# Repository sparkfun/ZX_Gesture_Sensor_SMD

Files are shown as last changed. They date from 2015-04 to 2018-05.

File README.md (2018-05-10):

SparkFun ZX Distance and Gesture Sensor
========================================

ZX Gesture Sensor

[*ZX Gesture Sensor (13162)*](https://www.sparkfun.com/products/13162)

The ZX Sensor works by bouncing infrared (IR) beams of light from the two LEDs on either side 
off of an object above the sensor. The bounced light returns to the receiver in the center of
the sensor, and a microcontroller on the back of the sensor interprets the data. We can read 
the results using an I2C or UART connection.

Repository Contents
-------------------

* **/Hardware** - Eagle design files (.brd, .sch)
* **/Libraries** - Arduino library and example code. For the most recent updates, make sure to check out the GitHub repo for the Arduino library linked below.
* **/Production** - Production panel files (.brd)

Documentation
--------------
* **[Library](https://github.com/sparkfun/SparkFun_ZX_Distance_and_Gesture_Sensor_Arduino_Library)** - Arduino library for the ZX Distance and Gesture Sensor.
* **[Hookup Guide](https://learn.sparkfun.com/tutorials/zx-distance-and-gesture-sensor-smd-hookup-guide)** - Basic hookup guide for the ZX Gesture Sensor.

License Information
-------------------

This product is _**open source**_! 

Please review the LICENSE.md file for license information. 

If you have any questions or concerns on licensing, please contact techsupport@sparkfun.com.

Distributed as-is; no warranty is given.

- Your friends at SparkFun.

__In Collaboration in XYZ Interactive__

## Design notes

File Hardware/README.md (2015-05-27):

SparkFun <PRODUCT NAME> Design Files
=====================================

The .sch and .brd files hare are Eagle CAD schematic and PCB design files from SparkFun Electronics.
A freeware version of Eagle can be found [here](http://www.cadsoftusa.com/download-eagle/freeware/).

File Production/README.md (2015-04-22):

SparkFun <PRODUCT NAME> Production Files
=========================================

These are the production files SparkFun uses for printing PCBs.

License Information
-------------------
This product is open source! 

The hardware is released under [Creative Commons ShareAlike 4.0 International](https://creativecommons.org/licenses/by-sa/4.0/).

Please use, reuse, and modify these files as you see fit. Please maintain attribution to SparkFun Electronics and release anything derivative under the same license.

Distributed as-is; no warranty is given.

- Your friends at SparkFun.

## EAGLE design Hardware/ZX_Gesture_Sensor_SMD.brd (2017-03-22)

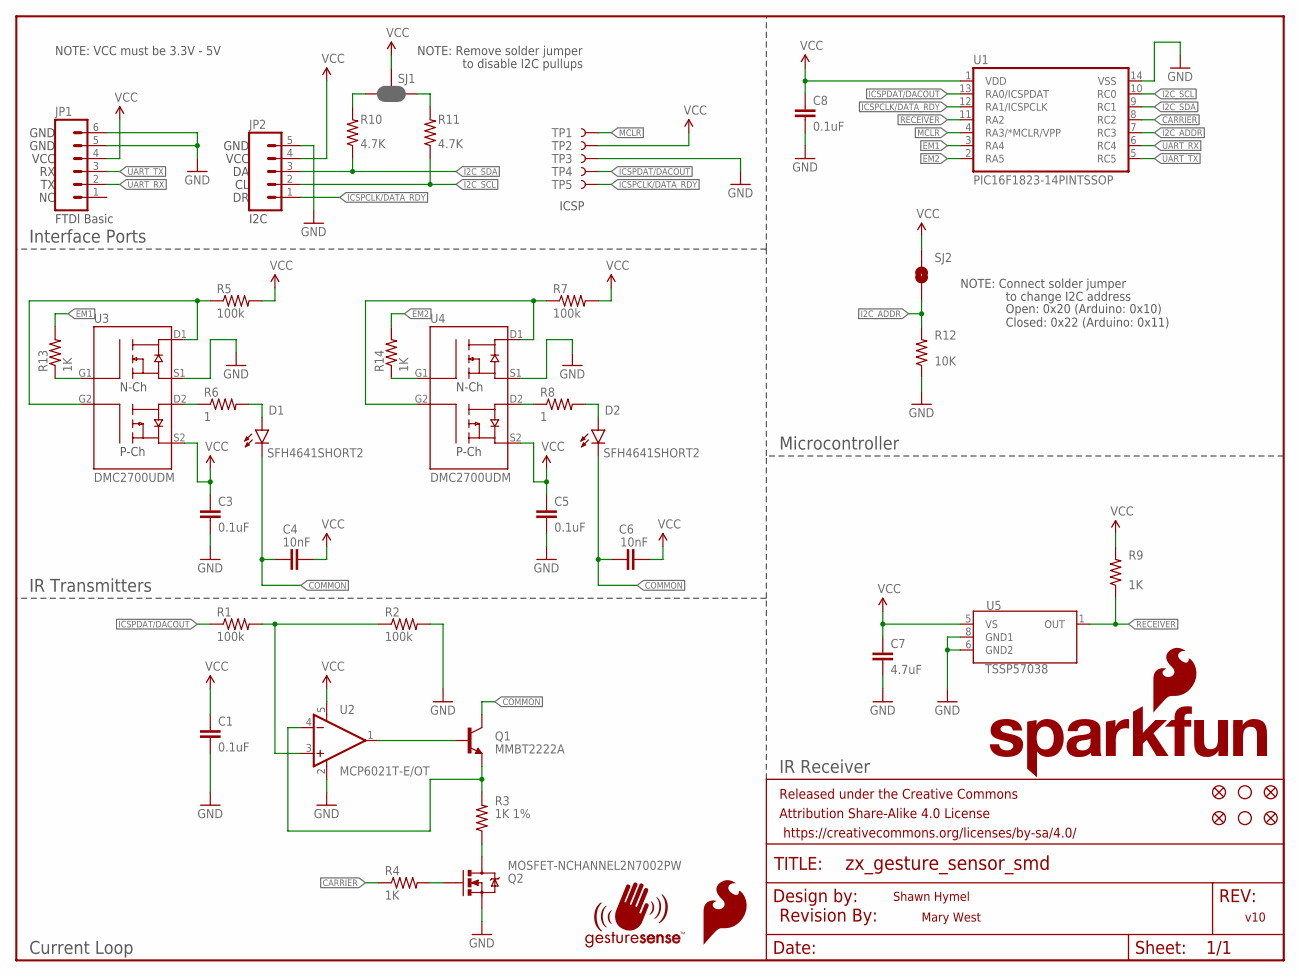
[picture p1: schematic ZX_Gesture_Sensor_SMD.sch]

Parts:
C1, C3, C5, C8: 0.1uF; 0603-CAP
C4, C6: 10nF; 0603-CAP
C7: 4.7uF; 0603-CAP
D1, D2: SFH4641SHORT2; SFH4641-SHORT2
FID1, FID2, FID3, FID4: FIDUCIALUFIDUCIAL; MICRO-FIDUCIAL
FRAME1: FRAME-LETTER; CREATIVE_COMMONS
JP1: M06NO_SILK_FEMALE_PTH; 1X06_NO_SILK
JP2: M05PTH; 1X05
LOGO1: REVISION
LOGO2: SFE_LOGO_FLAME.1_INCH; SFE_LOGO_FLAME_.1
Q1: MMBT2222A; SOT23-3
Q2: MOSFET-NCHANNEL2N7002PW; SOT323
R1, R2, R5, R7: 100k; 0603-RES
R3: 1K 1%; 0603-RES
R4, R9, R13, R14: 1K; 0603-RES
R6, R8: 1; 0603-RES
R10, R11: 4.7K; 0603-RES
R12: 10K; 0603-RES
SJ1: JUMPER-PAD-3-NC_BY_PASTE; PAD-JUMPER-3-NC_BY_PASTE_YES_SILK_FULL_BOX
SJ2: JUMPER-PAD-2-NOYES_SILK; PAD-JUMPER-2-NO_YES_SILK
STANDOFF1, STANDOFF2: STAND-OFF
TP1, TP2, TP3, TP4, TP5: TEST-POINT3X4; PAD.03X.04
U1: PIC16F1823-14PINTSSOP; TSSOP14
U2: MCP6021T-E/OT; SOT23-5
U3, U4: DMC2700UDM; SOT26
U5: TSSP57038; TSOP572
U$5: SFE_LOGO_NAME_FLAME.1_INCH; SFE_LOGO_NAME_FLAME_.1
U$6: GESTURESENSE_LOGOSTEXT; GESTURESENSE_TEXT

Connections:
CARRIER: R4.1, U1.8 (RC2)
COMMON: C4.1, C6.1, D1.C, D2.C, Q1.3 (C)
EM1: R13.2, U1.3 (RA4)
EM2: R14.2, U1.2 (RA5)
GND: C1.2, C3.2, C5.2, C7.2, C8.2, JP1.5, JP1.6, JP2.5, Q2.2 (S), R2.2, R12.1, TP3.P$1, U1.14 (VSS), U2.2 (V-), U3.S1, U4.S1, U5.6 (GND2), U5.8 (GND1)
I2C_ADDR: R12.2, SJ2.1, U1.7 (RC3)
I2C_SCL: JP2.2, R11.1, U1.10 (RC0)
I2C_SDA: JP2.3, R10.1, U1.9 (RC1)
ICSPCLK/DATA_RDY: JP2.1, TP5.P$1, U1.12 (RA1/ICSPCLK)
ICSPDAT/DACOUT: R1.1, TP4.P$1, U1.13 (RA0/ICSPDAT)
MCLR: TP1.P$1, U1.4 (RA3/*MCLR/VPP)
unnamed: R1.2, R2.1, U2.3 (+IN)
unnamed: Q1.2 (E), R3.2, U2.4 (-IN)
unnamed: Q1.1 (B), U2.1 (OUT)
unnamed: Q2.3 (D), R3.1
unnamed: Q2.1 (G), R4.2
unnamed: R6.1, U3.D2
unnamed: D1.A, R6.2
unnamed: R5.1, U3.D1, U3.G2
unnamed: R7.1, U4.D1, U4.G2
unnamed: R10.2, SJ1.3
unnamed: R8.1, U4.D2
unnamed: D2.A, R8.2
unnamed: R11.2, SJ1.1
unnamed: R13.1, U3.G1
unnamed: R14.1, U4.G1
RECEIVER: R9.1, U1.11 (RA2), U5.1 (OUT)
UART_RX: JP1.2, U1.6 (RC4)
UART_TX: JP1.3, U1.5 (RC5)
VCC: C1.1, C3.1, C4.2, C5.1, C6.2, C7.1, C8.1, JP1.4, JP2.4, R5.2, R7.2, R9.2, SJ1.2, SJ2.2, TP2.P$1, U1.1 (VDD), U2.5 (V+), U3.S2, U4.S2, U5.5 (VS)

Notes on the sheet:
FTDI Basic
I2C
ICSP
NOTE: Remove solder jumper
to disable I2C pullups
NOTE: Connect solder jumper
to change I2C address
Open: 0x20 (Arduino: 0x10) Closed: 0x22 (Arduino: 0x11)
Interface Ports
IR Transmitters
Current Loop
Microcontroller
IR Receiver
VCC
GND
NOTE: VCC must be 3.3V - 5V
Shawn Hymel
Mary West
v10

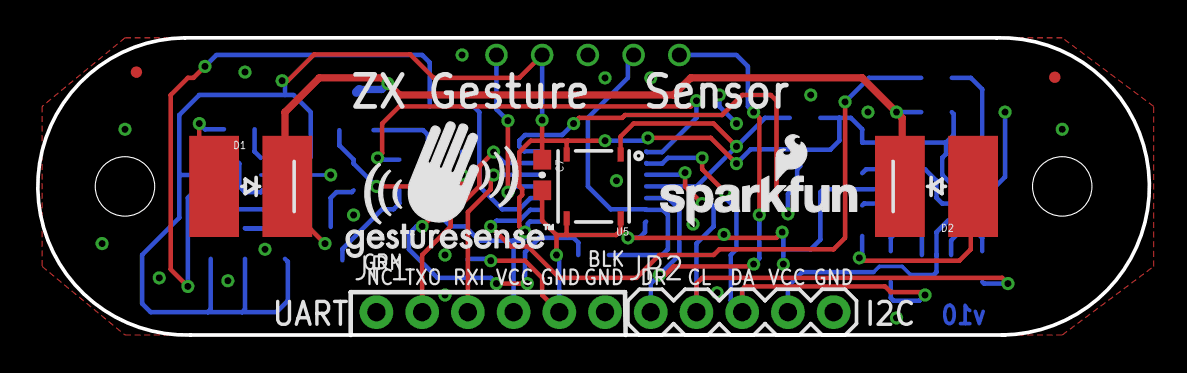
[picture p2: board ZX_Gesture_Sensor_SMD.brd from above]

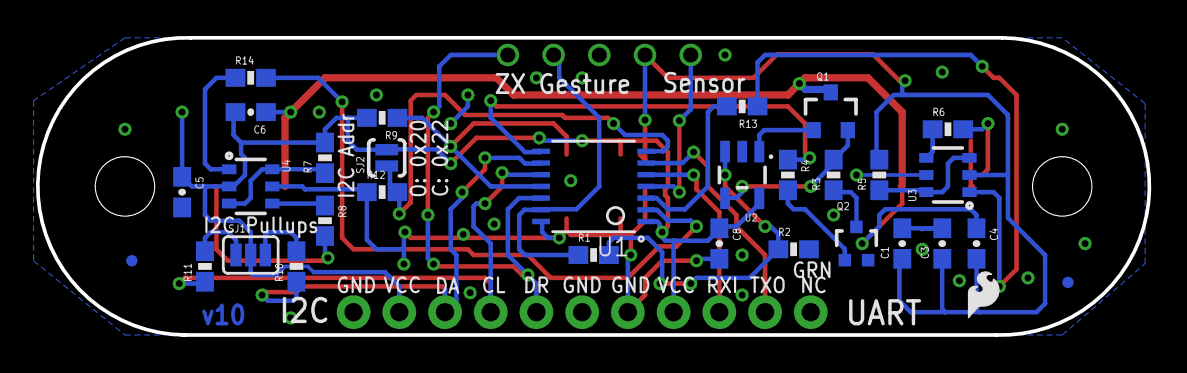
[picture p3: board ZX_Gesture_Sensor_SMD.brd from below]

Board: 2 copper layers, 61.8 x 16.5 mm, 50 parts (36 on the bottom side), 30 nets.

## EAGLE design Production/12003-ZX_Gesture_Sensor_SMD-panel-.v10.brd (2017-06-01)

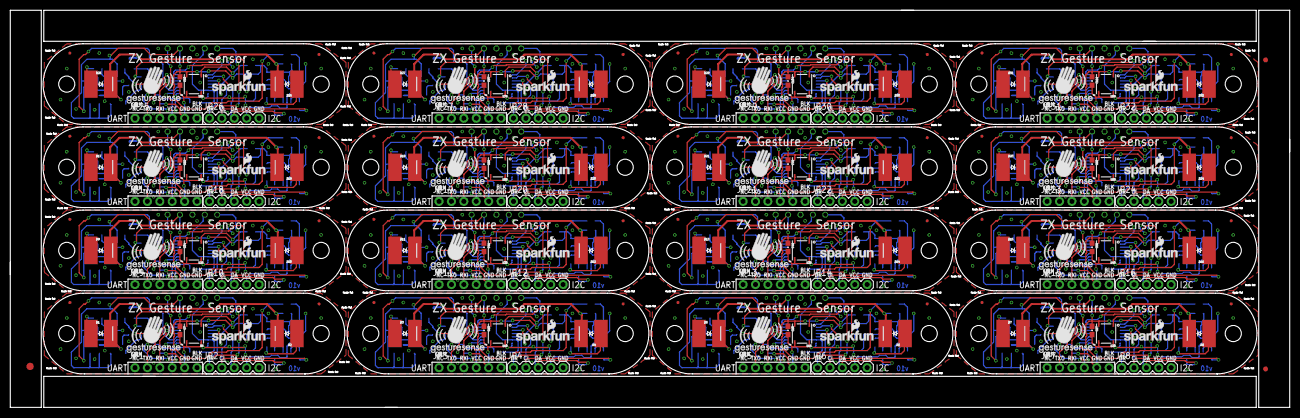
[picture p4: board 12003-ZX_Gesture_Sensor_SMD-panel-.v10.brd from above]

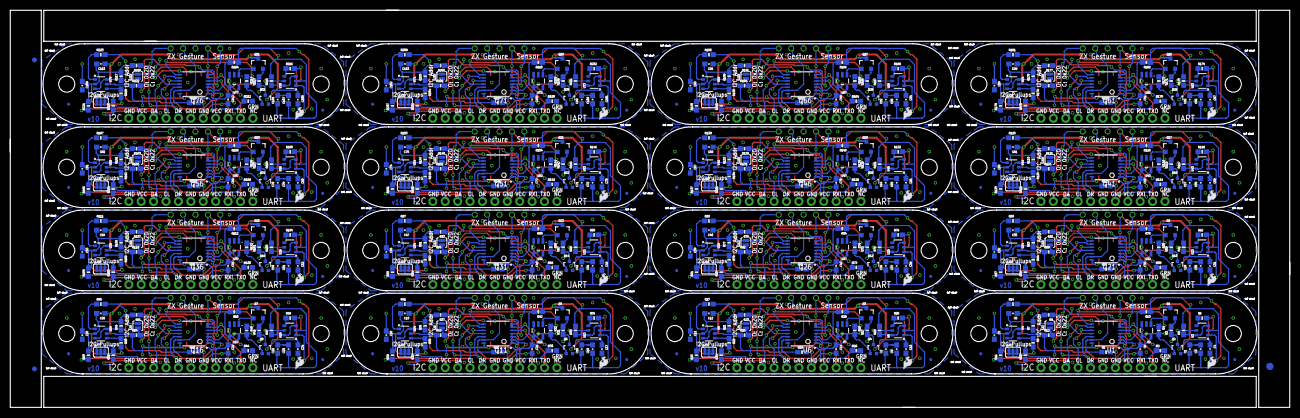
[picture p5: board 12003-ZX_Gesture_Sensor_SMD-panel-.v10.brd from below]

Board: 2 copper layers, 261.9 x 81.3 mm, 774 parts (579 on the bottom side), 480 nets.

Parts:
C1, C2, C3, C5, C8, C9, C11, C14, C15, C16, C18, C21, C22, C23, C25, C28, C29, C30, C32, C35, C36, C37, C39, C42, C43, C44, C46, C49, C50, C51, C53, C56, C57, C58, C60, C63, C64, C65, C67, C70, C71, C72, C74, C77, C78, C79, C81, C84, C85, C86, C88, C91, C92, C93, C95, C98, C99, C100, C102, C105, C106, C107, C109, C112: 0.1uF; 0603-CAP
C4, C6, C10, C12, C17, C19, C24, C26, C31, C33, C38, C40, C45, C47, C52, C54, C59, C61, C66, C68, C73, C75, C80, C82, C87, C89, C94, C96, C101, C103, C108, C110: 10nF; 0603-CAP
C7, C13, C20, C27, C34, C41, C48, C55, C62, C69, C76, C83, C90, C97, C104, C111: 4.7uF; 0603-CAP
D1, D2, D3, D4, D5, D6, D7, D8, D9, D10, D11, D12, D13, D14, D15, D16, D17, D18, D19, D20, D21, D22, D23, D24, D25, D26, D27, D28, D29, D30, D31, D32: SFH4641SHORT2; SFH4641-SHORT2
E$1, E$2: FIDUCIAL-1.5X3
E$3, E$4, E$7, E$8: FIDUCIAL-1X2
FID1, FID2, FID3, FID4, FID5, FID6, FID7, FID8, FID9, FID10, FID11, FID12, FID13, FID14, FID15, FID16, FID17, FID18, FID19, FID20, FID21, FID22, FID23, FID24, FID25, FID26, FID27, FID28, FID29, FID30, FID31, FID32, FID33, FID34, FID35, FID36, FID37, FID38, FID39, FID40, FID41, FID42, FID43, FID44, FID45, FID46, FID47, FID48, FID49, FID50, FID51, FID52, FID53, FID54, FID55, FID56, FID57, FID58, FID59, FID60, FID61, FID62, FID63, FID64: FIDUCIALUFIDUCIAL; MICRO-FIDUCIAL
JP1, JP3, JP5, JP7, JP9, JP11, JP13, JP15, JP17, JP19, JP21, JP23, JP25, JP27, JP29, JP31: 1X06_NO_SILK
JP2, JP4, JP6, JP8, JP10, JP12, JP14, JP16, JP18, JP20, JP22, JP24, JP26, JP28, JP30, JP32: 1X05
LOGO1, LOGO2, LOGO3, LOGO4, LOGO5, LOGO6, LOGO7, LOGO8, LOGO9, LOGO10, LOGO11, LOGO12, LOGO13, LOGO14, LOGO15, LOGO16: SFE_LOGO_FLAME.1_INCH; SFE_LOGO_FLAME_.1
Q1, Q3, Q5, Q7, Q9, Q11, Q13, Q15, Q17, Q19, Q21, Q23, Q25, Q27, Q29, Q31: MMBT2222A; SOT23-3
Q2, Q4, Q6, Q8, Q10, Q12, Q14, Q16, Q18, Q20, Q22, Q24, Q26, Q28, Q30, Q32: MOSFET-NCHANNEL2N7002PW; SOT323
R1, R2, R5, R7, R15, R16, R19, R21, R29, R30, R33, R35, R43, R44, R47, R49, R57, R58, R61, R63, R71, R72, R75, R77, R85, R86, R89, R91, R99, R100, R103, R105, R113, R114, R117, R119, R127, R128, R131, R133, R141, R142, R145, R147, R155, R156, R159, R161, R169, R170, R173, R175, R183, R184, R187, R189, R197, R198, R201, R203, R211, R212, R215, R217: 100k; 0603-RES
R3, R17, R31, R45, R59, R73, R87, R101, R115, R129, R143, R157, R171, R185, R199, R213: 1K 1%; 0603-RES
R4, R9, R13, R14, R18, R23, R27, R28, R32, R37, R41, R42, R46, R51, R55, R56, R60, R65, R69, R70, R74, R79, R83, R84, R88, R93, R97, R98, R102, R107, R111, R112, R116, R121, R125, R126, R130, R135, R139, R140, R144, R149, R153, R154, R158, R163, R167, R168, R172, R177, R181, R182, R186, R191, R195, R196, R200, R205, R209, R210, R214, R219, R223, R224: 1K; 0603-RES
R6, R8, R20, R22, R34, R36, R48, R50, R62, R64, R76, R78, R90, R92, R104, R106, R118, R120, R132, R134, R146, R148, R160, R162, R174, R176, R188, R190, R202, R204, R216, R218: 1; 0603-RES
R10, R11, R24, R25, R38, R39, R52, R53, R66, R67, R80, R81, R94, R95, R108, R109, R122, R123, R136, R137, R150, R151, R164, R165, R178, R179, R192, R193, R206, R207, R220, R221: 4.7K; 0603-RES
R12, R26, R40, R54, R68, R82, R96, R110, R124, R138, R152, R166, R180, R194, R208, R222: 10K; 0603-RES
SJ1, SJ3, SJ5, SJ7, SJ9, SJ11, SJ13, SJ15, SJ17, SJ19, SJ21, SJ23, SJ25, SJ27, SJ29, SJ31: JUMPER-PAD-3-NC_BY_PASTE; PAD-JUMPER-3-NC_BY_PASTE_YES_SILK_FULL_BOX
SJ2, SJ4, SJ6, SJ8, SJ10, SJ12, SJ14, SJ16, SJ18, SJ20, SJ22, SJ24, SJ26, SJ28, SJ30, SJ32: JUMPER-PAD-2-NOYES_SILK; PAD-JUMPER-2-NO_YES_SILK
STANDOFF1, STANDOFF2, STANDOFF3, STANDOFF4, STANDOFF5, STANDOFF6, STANDOFF7, STANDOFF8, STANDOFF9, STANDOFF10, STANDOFF11, STANDOFF12, STANDOFF13, STANDOFF14, STANDOFF15, STANDOFF16, STANDOFF17, STANDOFF18, STANDOFF19, STANDOFF20, STANDOFF21, STANDOFF22, STANDOFF23, STANDOFF24, STANDOFF25, STANDOFF26, STANDOFF27, STANDOFF28, STANDOFF29, STANDOFF30, STANDOFF31, STANDOFF32: STAND-OFF
TP1, TP2, TP3, TP4, TP5, TP6, TP7, TP8, TP9, TP10, TP11, TP12, TP13, TP14, TP15, TP16, TP17, TP18, TP19, TP20, TP21, TP22, TP23, TP24, TP25, TP26, TP27, TP28, TP29, TP30, TP31, TP32, TP33, TP34, TP35, TP36, TP37, TP38, TP39, TP40, TP41, TP42, TP43, TP44, TP45, TP46, TP47, TP48, TP49, TP50, TP51, TP52, TP53, TP54, TP55, TP56, TP57, TP58, TP59, TP60, TP61, TP62, TP63, TP64, TP65, TP66, TP67, TP68, TP69, TP70, TP71, TP72, TP73, TP74, TP75, TP76, TP77, TP78, TP79, TP80: TEST-POINT3X4; PAD.03X.04
U1, U6, U11, U16, U21, U26, U31, U36, U41, U46, U51, U56, U61, U66, U71, U76: PIC16F1823-14PINTSSOP; TSSOP14
U2, U7, U12, U17, U22, U27, U32, U37, U42, U47, U52, U57, U62, U67, U72, U77: MCP6021T-E/OT; SOT23-5
U3, U4, U8, U9, U13, U14, U18, U19, U23, U24, U28, U29, U33, U34, U38, U39, U43, U44, U48, U49, U53, U54, U58, U59, U63, U64, U68, U69, U73, U74, U78, U79: DMC2700UDM; SOT26
U5, U10, U15, U20, U25, U30, U35, U40, U45, U50, U55, U60, U65, U70, U75, U80: TSSP57038; TSOP572
U$1, U$3, U$5, U$7, U$9, U$11, U$13, U$15, U$17, U$19, U$21, U$23, U$25, U$27, U$29, U$31: SFE_LOGO_NAME_FLAME.1_INCH; SFE_LOGO_NAME_FLAME_.1
U$2, U$4, U$6, U$8, U$10, U$12, U$14, U$16, U$18, U$20, U$22, U$24, U$26, U$28, U$30, U$32: GESTURESENSE_LOGOSTEXT; GESTURESENSE_TEXT

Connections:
CARRIER: R4.1, U1.8
CARRIER1: R18.1, U6.8
CARRIER2: R32.1, U11.8
CARRIER3: R46.1, U16.8
CARRIER4: R60.1, U21.8
CARRIER5: R74.1, U26.8
CARRIER6: R88.1, U31.8
CARRIER7: R102.1, U36.8
CARRIER8: R116.1, U41.8
CARRIER9: R130.1, U46.8
CARRIER10: R144.1, U51.8
CARRIER11: R158.1, U56.8
CARRIER12: R172.1, U61.8
CARRIER13: R186.1, U66.8
CARRIER14: R200.1, U71.8
CARRIER15: R214.1, U76.8
COMMON: C4.1, C6.1, D1.C, D2.C, Q1.3
COMMON1: C10.1, C12.1, D3.C, D4.C, Q3.3
COMMON2: C17.1, C19.1, D5.C, D6.C, Q5.3
COMMON3: C24.1, C26.1, D7.C, D8.C, Q7.3
COMMON4: C31.1, C33.1, D9.C, D10.C, Q9.3
COMMON5: C38.1, C40.1, D11.C, D12.C, Q11.3
COMMON6: C45.1, C47.1, D13.C, D14.C, Q13.3
COMMON7: C52.1, C54.1, D15.C, D16.C, Q15.3
COMMON8: C59.1, C61.1, D17.C, D18.C, Q17.3
COMMON9: C66.1, C68.1, D19.C, D20.C, Q19.3
COMMON10: C73.1, C75.1, D21.C, D22.C, Q21.3
COMMON11: C80.1, C82.1, D23.C, D24.C, Q23.3
COMMON12: C87.1, C89.1, D25.C, D26.C, Q25.3
COMMON13: C94.1, C96.1, D27.C, D28.C, Q27.3
COMMON14: C101.1, C103.1, D29.C, D30.C, Q29.3
COMMON15: C108.1, C110.1, D31.C, D32.C, Q31.3
EM1: R13.2, U1.3
EM2: R14.2, U1.2
EM3: R28.2, U6.3
EM4: R27.2, U6.2
EM5: R42.2, U11.3
EM6: R41.2, U11.2
EM7: R56.2, U16.3
EM8: R55.2, U16.2
EM9: R70.2, U21.3
EM10: R69.2, U21.2
EM11: R84.2, U26.3
EM12: R83.2, U26.2
EM13: R98.2, U31.3
EM14: R97.2, U31.2
EM15: R112.2, U36.3
EM16: R111.2, U36.2
EM17: R126.2, U41.3
EM18: R125.2, U41.2
EM19: R140.2, U46.3
EM20: R139.2, U46.2
EM21: R154.2, U51.3
EM22: R153.2, U51.2
EM23: R168.2, U56.3
EM24: R167.2, U56.2
EM25: R182.2, U61.3
EM26: R181.2, U61.2
EM27: R196.2, U66.3
EM28: R195.2, U66.2
EM29: R210.2, U71.3
EM30: R209.2, U71.2
EM31: R224.2, U76.3
EM32: R223.2, U76.2
GND: C1.2, C3.2, C5.2, C7.2, C8.2, JP1.5, JP1.6, JP2.5, Q2.2, R2.2, R12.1, TP3.P$1, U1.14, U2.2, U3.S1, U4.S1, U5.6, U5.8
GND1: C2.2, C9.2, C11.2, C13.2, C14.2, JP3.5, JP3.6, JP4.5, Q4.2, R16.2, R26.1, TP7.P$1, U6.14, U7.2, U8.S1, U9.S1, U10.6, U10.8
GND2: C15.2, C16.2, C18.2, C20.2, C21.2, JP5.5, JP5.6, JP6.5, Q6.2, R30.2, R40.1, TP12.P$1, U11.14, U12.2, U13.S1, U14.S1, U15.6, U15.8
GND3: C22.2, C23.2, C25.2, C27.2, C28.2, JP7.5, JP7.6, JP8.5, Q8.2, R44.2, R54.1, TP17.P$1, U16.14, U17.2, U18.S1, U19.S1, U20.6, U20.8
GND4: C29.2, C30.2, C32.2, C34.2, C35.2, JP9.5, JP9.6, JP10.5, Q10.2, R58.2, R68.1, TP22.P$1, U21.14, U22.2, U23.S1, U24.S1, U25.6, U25.8
GND5: C36.2, C37.2, C39.2, C41.2, C42.2, JP11.5, JP11.6, JP12.5, Q12.2, R72.2, R82.1, TP27.P$1, U26.14, U27.2, U28.S1, U29.S1, U30.6, U30.8
GND6: C43.2, C44.2, C46.2, C48.2, C49.2, JP13.5, JP13.6, JP14.5, Q14.2, R86.2, R96.1, TP32.P$1, U31.14, U32.2, U33.S1, U34.S1, U35.6, U35.8
GND7: C50.2, C51.2, C53.2, C55.2, C56.2, JP15.5, JP15.6, JP16.5, Q16.2, R100.2, R110.1, TP37.P$1, U36.14, U37.2, U38.S1, U39.S1, U40.6, U40.8
GND8: C57.2, C58.2, C60.2, C62.2, C63.2, JP17.5, JP17.6, JP18.5, Q18.2, R114.2, R124.1, TP42.P$1, U41.14, U42.2, U43.S1, U44.S1, U45.6, U45.8
GND9: C64.2, C65.2, C67.2, C69.2, C70.2, JP19.5, JP19.6, JP20.5, Q20.2, R128.2, R138.1, TP47.P$1, U46.14, U47.2, U48.S1, U49.S1, U50.6, U50.8
GND10: C71.2, C72.2, C74.2, C76.2, C77.2, JP21.5, JP21.6, JP22.5, Q22.2, R142.2, R152.1, TP52.P$1, U51.14, U52.2, U53.S1, U54.S1, U55.6, U55.8
GND11: C78.2, C79.2, C81.2, C83.2, C84.2, JP23.5, JP23.6, JP24.5, Q24.2, R156.2, R166.1, TP57.P$1, U56.14, U57.2, U58.S1, U59.S1, U60.6, U60.8
GND12: C85.2, C86.2, C88.2, C90.2, C91.2, JP25.5, JP25.6, JP26.5, Q26.2, R170.2, R180.1, TP62.P$1, U61.14, U62.2, U63.S1, U64.S1, U65.6, U65.8
GND13: C92.2, C93.2, C95.2, C97.2, C98.2, JP27.5, JP27.6, JP28.5, Q28.2, R184.2, R194.1, TP67.P$1, U66.14, U67.2, U68.S1, U69.S1, U70.6, U70.8
GND14: C99.2, C100.2, C102.2, C104.2, C105.2, JP29.5, JP29.6, JP30.5, Q30.2, R198.2, R208.1, TP72.P$1, U71.14, U72.2, U73.S1, U74.S1, U75.6, U75.8
GND15: C106.2, C107.2, C109.2, C111.2, C112.2, JP31.5, JP31.6, JP32.5, Q32.2, R212.2, R222.1, TP77.P$1, U76.14, U77.2, U78.S1, U79.S1, U80.6, U80.8
I2C_ADDR: R12.2, SJ2.1, U1.7
I2C_ADDR1: R26.2, SJ4.1, U6.7
I2C_ADDR2: R40.2, SJ6.1, U11.7
I2C_ADDR3: R54.2, SJ8.1, U16.7
I2C_ADDR4: R68.2, SJ10.1, U21.7
I2C_ADDR5: R82.2, SJ12.1, U26.7
I2C_ADDR6: R96.2, SJ14.1, U31.7
I2C_ADDR7: R110.2, SJ16.1, U36.7
I2C_ADDR8: R124.2, SJ18.1, U41.7
I2C_ADDR9: R138.2, SJ20.1, U46.7
I2C_ADDR10: R152.2, SJ22.1, U51.7
I2C_ADDR11: R166.2, SJ24.1, U56.7
I2C_ADDR12: R180.2, SJ26.1, U61.7
I2C_ADDR13: R194.2, SJ28.1, U66.7
I2C_ADDR14: R208.2, SJ30.1, U71.7
I2C_ADDR15: R222.2, SJ32.1, U76.7
I2C_SCL: JP2.2, R11.1, U1.10
I2C_SCL1: JP4.2, R25.1, U6.10
I2C_SCL2: JP6.2, R39.1, U11.10
I2C_SCL3: JP8.2, R53.1, U16.10
I2C_SCL4: JP10.2, R67.1, U21.10
I2C_SCL5: JP12.2, R81.1, U26.10
I2C_SCL6: JP14.2, R95.1, U31.10
I2C_SCL7: JP16.2, R109.1, U36.10
I2C_SCL8: JP18.2, R123.1, U41.10
I2C_SCL9: JP20.2, R137.1, U46.10
I2C_SCL10: JP22.2, R151.1, U51.10
I2C_SCL11: JP24.2, R165.1, U56.10
I2C_SCL12: JP26.2, R179.1, U61.10
I2C_SCL13: JP28.2, R193.1, U66.10
I2C_SCL14: JP30.2, R207.1, U71.10
I2C_SCL15: JP32.2, R221.1, U76.10
I2C_SDA: JP2.3, R10.1, U1.9
I2C_SDA1: JP4.3, R24.1, U6.9
I2C_SDA2: JP6.3, R38.1, U11.9
I2C_SDA3: JP8.3, R52.1, U16.9
I2C_SDA4: JP10.3, R66.1, U21.9
I2C_SDA5: JP12.3, R80.1, U26.9
I2C_SDA6: JP14.3, R94.1, U31.9
I2C_SDA7: JP16.3, R108.1, U36.9
I2C_SDA8: JP18.3, R122.1, U41.9
I2C_SDA9: JP20.3, R136.1, U46.9
I2C_SDA10: JP22.3, R150.1, U51.9
I2C_SDA11: JP24.3, R164.1, U56.9
I2C_SDA12: JP26.3, R178.1, U61.9
I2C_SDA13: JP28.3, R192.1, U66.9
I2C_SDA14: JP30.3, R206.1, U71.9
I2C_SDA15: JP32.3, R220.1, U76.9
ICSPCLK/DATA_RDY: JP2.1, TP5.P$1, U1.12
ICSPCLK/DATA_RDY1: JP4.1, TP9.P$1, U6.12
ICSPCLK/DATA_RDY2: JP6.1, TP14.P$1, U11.12
ICSPCLK/DATA_RDY3: JP8.1, TP19.P$1, U16.12
ICSPCLK/DATA_RDY4: JP10.1, TP24.P$1, U21.12
ICSPCLK/DATA_RDY5: JP12.1, TP29.P$1, U26.12
ICSPCLK/DATA_RDY6: JP14.1, TP34.P$1, U31.12
ICSPCLK/DATA_RDY7: JP16.1, TP39.P$1, U36.12
ICSPCLK/DATA_RDY8: JP18.1, TP44.P$1, U41.12
ICSPCLK/DATA_RDY9: JP20.1, TP49.P$1, U46.12
ICSPCLK/DATA_RDY10: JP22.1, TP54.P$1, U51.12
ICSPCLK/DATA_RDY11: JP24.1, TP59.P$1, U56.12
ICSPCLK/DATA_RDY12: JP26.1, TP64.P$1, U61.12
ICSPCLK/DATA_RDY13: JP28.1, TP69.P$1, U66.12
ICSPCLK/DATA_RDY14: JP30.1, TP74.P$1, U71.12
ICSPCLK/DATA_RDY15: JP32.1, TP79.P$1, U76.12
ICSPDAT/DACOUT: R1.1, TP4.P$1, U1.13
ICSPDAT/DACOUT1: R15.1, TP10.P$1, U6.13
ICSPDAT/DACOUT2: R29.1, TP15.P$1, U11.13
ICSPDAT/DACOUT3: R43.1, TP20.P$1, U16.13
ICSPDAT/DACOUT4: R57.1, TP25.P$1, U21.13
ICSPDAT/DACOUT5: R71.1, TP30.P$1, U26.13
ICSPDAT/DACOUT6: R85.1, TP35.P$1, U31.13
ICSPDAT/DACOUT7: R99.1, TP40.P$1, U36.13
ICSPDAT/DACOUT8: R113.1, TP45.P$1, U41.13
ICSPDAT/DACOUT9: R127.1, TP50.P$1, U46.13
ICSPDAT/DACOUT10: R141.1, TP55.P$1, U51.13
ICSPDAT/DACOUT11: R155.1, TP60.P$1, U56.13
ICSPDAT/DACOUT12: R169.1, TP65.P$1, U61.13
ICSPDAT/DACOUT13: R183.1, TP70.P$1, U66.13
ICSPDAT/DACOUT14: R197.1, TP75.P$1, U71.13
ICSPDAT/DACOUT15: R211.1, TP80.P$1, U76.13
MCLR: TP1.P$1, U1.4
MCLR1: TP8.P$1, U6.4
MCLR2: TP13.P$1, U11.4
MCLR3: TP18.P$1, U16.4
MCLR4: TP23.P$1, U21.4
MCLR5: TP28.P$1, U26.4
MCLR6: TP33.P$1, U31.4
MCLR7: TP38.P$1, U36.4
MCLR8: TP43.P$1, U41.4
MCLR9: TP48.P$1, U46.4
MCLR10: TP53.P$1, U51.4
MCLR11: TP58.P$1, U56.4
MCLR12: TP63.P$1, U61.4
MCLR13: TP68.P$1, U66.4
MCLR14: TP73.P$1, U71.4
MCLR15: TP78.P$1, U76.4
unnamed: R1.2, R2.1, U2.3
unnamed: Q1.2, R3.2, U2.4
unnamed: Q1.1, U2.1
unnamed: Q2.3, R3.1
unnamed: Q2.1, R4.2
unnamed: R6.1, U3.D2
unnamed: D1.A, R6.2
unnamed: R5.1, U3.D1, U3.G2
unnamed: R7.1, U4.D1, U4.G2
unnamed: R10.2, SJ1.3
unnamed: R8.1, U4.D2
unnamed: D2.A, R8.2
unnamed: R11.2, SJ1.1
unnamed: R13.1, U3.G1
unnamed: R14.1, U4.G1
unnamed: R15.2, R16.1, U7.3
unnamed: Q3.1, U7.1
unnamed: Q4.3, R17.1
unnamed: Q4.1, R18.2
unnamed: Q3.2, R17.2, U7.4
unnamed: R20.1, U8.D2
unnamed: D3.A, R20.2
unnamed: R19.1, U8.D1, U8.G2
unnamed: R21.1, U9.D1, U9.G2
unnamed: R22.1, U9.D2
unnamed: R24.2, SJ3.3
unnamed: R25.2, SJ3.1
unnamed: R27.1, U9.G1
unnamed: R28.1, U8.G1
unnamed: D4.A, R22.2
unnamed: R29.2, R30.1, U12.3
unnamed: Q5.1, U12.1
unnamed: Q6.3, R31.1
unnamed: Q6.1, R32.2
unnamed: Q5.2, R31.2, U12.4
unnamed: R34.1, U13.D2
unnamed: D5.A, R34.2
unnamed: R33.1, U13.D1, U13.G2
unnamed: R35.1, U14.D1, U14.G2
unnamed: R36.1, U14.D2
unnamed: R38.2, SJ5.3
unnamed: R39.2, SJ5.1
unnamed: R41.1, U14.G1
unnamed: R42.1, U13.G1
unnamed: D6.A, R36.2
unnamed: R43.2, R44.1, U17.3
unnamed: Q7.1, U17.1
unnamed: Q8.3, R45.1
unnamed: Q8.1, R46.2
unnamed: Q7.2, R45.2, U17.4
unnamed: R48.1, U18.D2
unnamed: D7.A, R48.2
unnamed: R47.1, U18.D1, U18.G2
unnamed: R49.1, U19.D1, U19.G2
unnamed: R50.1, U19.D2
unnamed: R52.2, SJ7.3
unnamed: R53.2, SJ7.1
unnamed: R55.1, U19.G1
unnamed: R56.1, U18.G1
unnamed: D8.A, R50.2
unnamed: R57.2, R58.1, U22.3
unnamed: Q9.1, U22.1
unnamed: Q10.3, R59.1
unnamed: Q10.1, R60.2
unnamed: Q9.2, R59.2, U22.4
unnamed: R62.1, U23.D2
unnamed: D9.A, R62.2
unnamed: R61.1, U23.D1, U23.G2
unnamed: R63.1, U24.D1, U24.G2
unnamed: R64.1, U24.D2
unnamed: R66.2, SJ9.3
unnamed: R67.2, SJ9.1
unnamed: R69.1, U24.G1
unnamed: R70.1, U23.G1
unnamed: D10.A, R64.2
unnamed: R71.2, R72.1, U27.3
unnamed: Q11.1, U27.1
unnamed: Q12.3, R73.1
unnamed: Q12.1, R74.2
unnamed: Q11.2, R73.2, U27.4
unnamed: R76.1, U28.D2
unnamed: D11.A, R76.2
unnamed: R75.1, U28.D1, U28.G2
unnamed: R77.1, U29.D1, U29.G2
unnamed: R78.1, U29.D2
unnamed: R80.2, SJ11.3
unnamed: R81.2, SJ11.1
unnamed: R83.1, U29.G1
unnamed: R84.1, U28.G1
unnamed: D12.A, R78.2
unnamed: R85.2, R86.1, U32.3
unnamed: Q13.1, U32.1
unnamed: Q14.3, R87.1
unnamed: Q14.1, R88.2
unnamed: Q13.2, R87.2, U32.4
unnamed: R90.1, U33.D2
unnamed: D13.A, R90.2
unnamed: R89.1, U33.D1, U33.G2
unnamed: R91.1, U34.D1, U34.G2
unnamed: R92.1, U34.D2
unnamed: R94.2, SJ13.3
unnamed: R95.2, SJ13.1
unnamed: R97.1, U34.G1
unnamed: R98.1, U33.G1
unnamed: D14.A, R92.2
unnamed: R99.2, R100.1, U37.3
unnamed: Q15.1, U37.1
unnamed: Q16.3, R101.1
unnamed: Q16.1, R102.2
unnamed: Q15.2, R101.2, U37.4
unnamed: R104.1, U38.D2
unnamed: D15.A, R104.2
unnamed: R103.1, U38.D1, U38.G2
unnamed: R105.1, U39.D1, U39.G2
unnamed: R106.1, U39.D2
unnamed: R108.2, SJ15.3
unnamed: R109.2, SJ15.1
unnamed: R111.1, U39.G1
unnamed: R112.1, U38.G1
unnamed: D16.A, R106.2
unnamed: R113.2, R114.1, U42.3
unnamed: Q17.1, U42.1
unnamed: Q18.3, R115.1
unnamed: Q18.1, R116.2
unnamed: Q17.2, R115.2, U42.4
unnamed: R118.1, U43.D2
unnamed: D17.A, R118.2
unnamed: R117.1, U43.D1, U43.G2
unnamed: R119.1, U44.D1, U44.G2
unnamed: R120.1, U44.D2
unnamed: R122.2, SJ17.3
unnamed: R123.2, SJ17.1
unnamed: R125.1, U44.G1
unnamed: R126.1, U43.G1
unnamed: D18.A, R120.2
unnamed: R127.2, R128.1, U47.3
unnamed: Q19.1, U47.1
unnamed: Q20.3, R129.1
unnamed: Q20.1, R130.2
unnamed: Q19.2, R129.2, U47.4
unnamed: R132.1, U48.D2
unnamed: D19.A, R132.2
unnamed: R131.1, U48.D1, U48.G2
unnamed: R133.1, U49.D1, U49.G2
unnamed: R134.1, U49.D2
unnamed: R136.2, SJ19.3
unnamed: R137.2, SJ19.1
unnamed: R139.1, U49.G1
unnamed: R140.1, U48.G1
unnamed: D20.A, R134.2
unnamed: R141.2, R142.1, U52.3
unnamed: Q21.1, U52.1
unnamed: Q22.3, R143.1
unnamed: Q22.1, R144.2
unnamed: Q21.2, R143.2, U52.4
unnamed: R146.1, U53.D2
unnamed: D21.A, R146.2
unnamed: R145.1, U53.D1, U53.G2
unnamed: R147.1, U54.D1, U54.G2
unnamed: R148.1, U54.D2
unnamed: R150.2, SJ21.3
unnamed: R151.2, SJ21.1
unnamed: R153.1, U54.G1
unnamed: R154.1, U53.G1
unnamed: D22.A, R148.2
unnamed: R155.2, R156.1, U57.3
unnamed: Q23.1, U57.1
unnamed: Q24.3, R157.1
unnamed: Q24.1, R158.2
unnamed: Q23.2, R157.2, U57.4
unnamed: R160.1, U58.D2
unnamed: D23.A, R160.2
unnamed: R159.1, U58.D1, U58.G2
unnamed: R161.1, U59.D1, U59.G2
unnamed: R162.1, U59.D2
unnamed: R164.2, SJ23.3
unnamed: R165.2, SJ23.1
unnamed: R167.1, U59.G1
unnamed: R168.1, U58.G1
unnamed: D24.A, R162.2
unnamed: R169.2, R170.1, U62.3
unnamed: Q25.1, U62.1
unnamed: Q26.3, R171.1
unnamed: Q26.1, R172.2
unnamed: Q25.2, R171.2, U62.4
unnamed: R174.1, U63.D2
unnamed: D25.A, R174.2
unnamed: R173.1, U63.D1, U63.G2
unnamed: R175.1, U64.D1, U64.G2
unnamed: R176.1, U64.D2
unnamed: R178.2, SJ25.3
unnamed: R179.2, SJ25.1
unnamed: R181.1, U64.G1
unnamed: R182.1, U63.G1
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

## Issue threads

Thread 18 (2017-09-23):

Lots of information missing required to build this board

haldean, 2017-09-23:
Hi there! Both the firmware for the PIC controller on the board and the source for the ZX arduino library are missing from this repository, which means that there's not enough information to make one of these. Were these just accidentally excluded? It looks like there's directories for them to go in, there's just nothing in the Firmware or Software folders.

loricrotser, 2018-03-30:
Hi!

Since this is a project for the arduino, we don't have the firmware for the PIC controller uploaded here. The header and cpp are available for modification, and it may be that someone has done this already. The [forums](https://forum.sparkfun.com/) may have more information on this.

The libraries are housed in their own repo - I have updated the pull link in the readme here. The libraries can also be downloaded from the [hookup guide](https://learn.sparkfun.com/tutorials/zx-distance-and-gesture-sensor-smd-hookup-guide).

Hope this helps!

ShawnHymel, 2018-03-30:
@haldean If you are referring to the firmware on the PIC that's on the ZX board itself, that firmware is not open source. The ZX sensor was created as a collaboration between SparkFun and [XYZ Interactive](http://www.xyzinteractive.com/gesturesense-gesture_sensor_supplier/). We are able to open source the hardware, but XYZ still owns the intellectual property on the firmware. You are welcome to reach out to them if you would like to produce your own sensors.

haldean, 2018-03-30:
@ShawnHymel @loricrotser Then I'd request you remove the statement that this product is open source from the README. If the software it runs isn't open source, then the product isn't open source.

Closed 2018-03-30.

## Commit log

2015-04-22 Updating to new hardware repo layout, modifying READMEs
    [SN74HC165 Shift-In Breakout-Panel-v12.brd, Simon.brd, Simon.sch]
2015-04-22 More formatting cleanup
    [ArduinoUnoProtectionBoxR3.stl]
2016-02-11 Update LICENSE.md
    Updated year to be current
2016-03-22 Added New SCH and BRD Files
    [ZX_Gesture_Sensor_SMD.brd, ZX_Gesture_Sensor_SMD.sch]
2016-03-22 Updated Board File
    [ZX_Gesture_Sensor_SMD.brd, ZX_Gesture_Sensor_SMD.sch]
2016-03-22 Updated -- Placed Vias over test points
    [ZX_Gesture_Sensor_SMD.brd]
2016-03-31 Updated Board and Schematic Files
    [ZX_Gesture_Sensor_SMD_v02.brd, ZX_Gesture_Sensor_SMD_v02.sch]
2016-03-31 Updated Board and Schematic per QC
    [ZX_Gesture_Sensor_SMD_v02.brd, ZX_Gesture_Sensor_SMD_v02.sch]
2016-03-31 Updated Board Files per QC
    [ZX_Gesture_Sensor_SMD_v02.brd]
2016-03-31 Updated Sch
    [ZX_Gesture_Sensor_SMD_v02.sch]
2016-05-03 Updated Brd File
    [ZX_Gesture_Sensor_SMD_v02.brd]
2016-05-04 Moved Programming Pins
    [ZX_Gesture_Sensor_SMD_v02.brd]
2016-05-09 Updated Silk to include I2C adresses
    [ZX_Gesture_Sensor_SMD_v02.brd]
2016-05-11 Changed Sch font to vector
    [ZX_Gesture_Sensor_SMD_v02.sch]
2016-05-27 Updated board file to v03 for protos
    [ZX_Gesture_Sensor_SMD_v03.brd, ZX_Gesture_Sensor_SMD_v03.sch]
2016-05-31 Updated Brd and Sch Files per QC review
    [ZX_Gesture_Sensor_SMD.brd, ZX_Gesture_Sensor_SMD.sch, ZX_Gesture_Sensor_SMD_v03.brd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]
2016-05-31 cleaning up repo
    [ZX_Gesture_Sensor_SMD_v02.brd, ZX_Gesture_Sensor_SMD_v02.sch]
2016-09-08 V04 changes
    [ZX_Gesture_Sensor_SMD.brd, ZX_Gesture_Sensor_SMD.sch]
2016-09-14 Updated Brd File per Engineering Design Review
    [ZX_Gesture_Sensor_SMD.brd, ZX_Gesture_Sensor_SMD.sch]
2016-09-14 Updated Brd/Sch files per QC Review
    [ZX_Gesture_Sensor_SMD.brd, ZX_Gesture_Sensor_SMD.sch]
2017-01-31 Updated SCH & BRD Files
    [ZX_Gesture_Sensor_SMD.brd, ZX_Gesture_Sensor_SMD.sch]
2017-01-31 Updated BRD and SCH files
    [ZX_Gesture_Sensor_SMD.brd, ZX_Gesture_Sensor_SMD.sch]
2017-01-31 updated BRD Files
    [ZX_Gesture_Sensor_SMD.brd]
2017-02-06 Updated BRD and SCH Files per Design Review
    [ZX_Gesture_Sensor_SMD.brd]
2017-03-20 -Updated v05 to v10 -moved back silk labels -all copper is unchanged from v05.
    [ZX_Gesture_Sensor_SMD.brd, ZX_Gesture_Sensor_SMD.sch]
2017-03-22 -Approved DRC Erros -- Overalapping Vias and Test Points 3/22/2017
    [ZX_Gesture_Sensor_SMD.brd]
2018-05-10 Squashed 'Libraries/Arduino/' content from commit f6afaee
    git-subtree-dir: Libraries/Arduino
    git-subtree-split: f6afaeef8426aa26ab8c341ea9467d33714c12cb
2018-05-10 Squashed 'Libraries/Arduino/' changes from f6afaee..694cfb5
    694cfb5 Update README.md
    git-subtree-split: 694cfb57b9462c667afe94eeebdc14f0e5bf3b9e
    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

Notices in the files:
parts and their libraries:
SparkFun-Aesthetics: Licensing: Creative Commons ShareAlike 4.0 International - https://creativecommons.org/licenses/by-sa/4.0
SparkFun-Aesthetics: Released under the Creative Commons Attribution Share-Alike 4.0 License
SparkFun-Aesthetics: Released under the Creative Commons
